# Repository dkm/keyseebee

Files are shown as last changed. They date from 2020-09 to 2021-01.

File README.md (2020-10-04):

# PouetPouet

The firmware is [Keyberon](https://github.com/TeXitoi/keyberon), a
pure rust firmware.

## Features

 * 60 keys, using Cherry MX switches, only 1U keycaps;
 * USB-C connector;
 * 1 STM32F072 MCU, with hardware USB DFU bootloader and crystal less USB;
 * Only onboard SMD component (except for the switches).

## Inspiration

 * [Keyseebee](https://github.com/TeXitoi/keyseebee) for being the «I will change it quickly and have something ready in an hour» base project (even if I ended up redoing most of the hardware design).
 * [Steamvan](https://github.com/jmdaly/steamvan) for some KiCad design ideas;
 * [help-14](https://github.com/help-14/mechanical-keyboard) for making a nice list of existing keyboard;
 * [Masterzen](http://www.masterzen.fr/2020/05/03/designing-a-keyboard-part-1/) and many others for writing online tutorials for newbies like me.

## Bill Of Materials

|Item |Package|Qty|Remarks |Price |
|---|---|--:|---|-----:|

## Compiling and flashing

Install the complete toolchain and utils:

```shell
curl https://sh.rustup.rs -sSf | sh
rustup target add thumbv6m-none-eabi
rustup component add llvm-tools-preview
cargo install cargo-binutils
sudo apt-get install dfu-util
```

Compile:

```shell
cd firmware
cargo objcopy --bin pouetpouet --release -- -O binary pouetpouet.bin
```

To flash using dfu-util, first put the board in dfu mode by pressing
BOOT, pressing and releasing RESET and releasing BOOT. Then:

```shell
dfu-util -d 0483:df11 -a 0 -s 0x08000000:leave -D pouetpouet.bin
```

The fist time, if the write fail, your flash might be protected. To
unprotect:

```shell
dfu-util -d 0483:df11 -a 0 -s 0x08000000:force:unprotect -D pouetpouet.bin
```

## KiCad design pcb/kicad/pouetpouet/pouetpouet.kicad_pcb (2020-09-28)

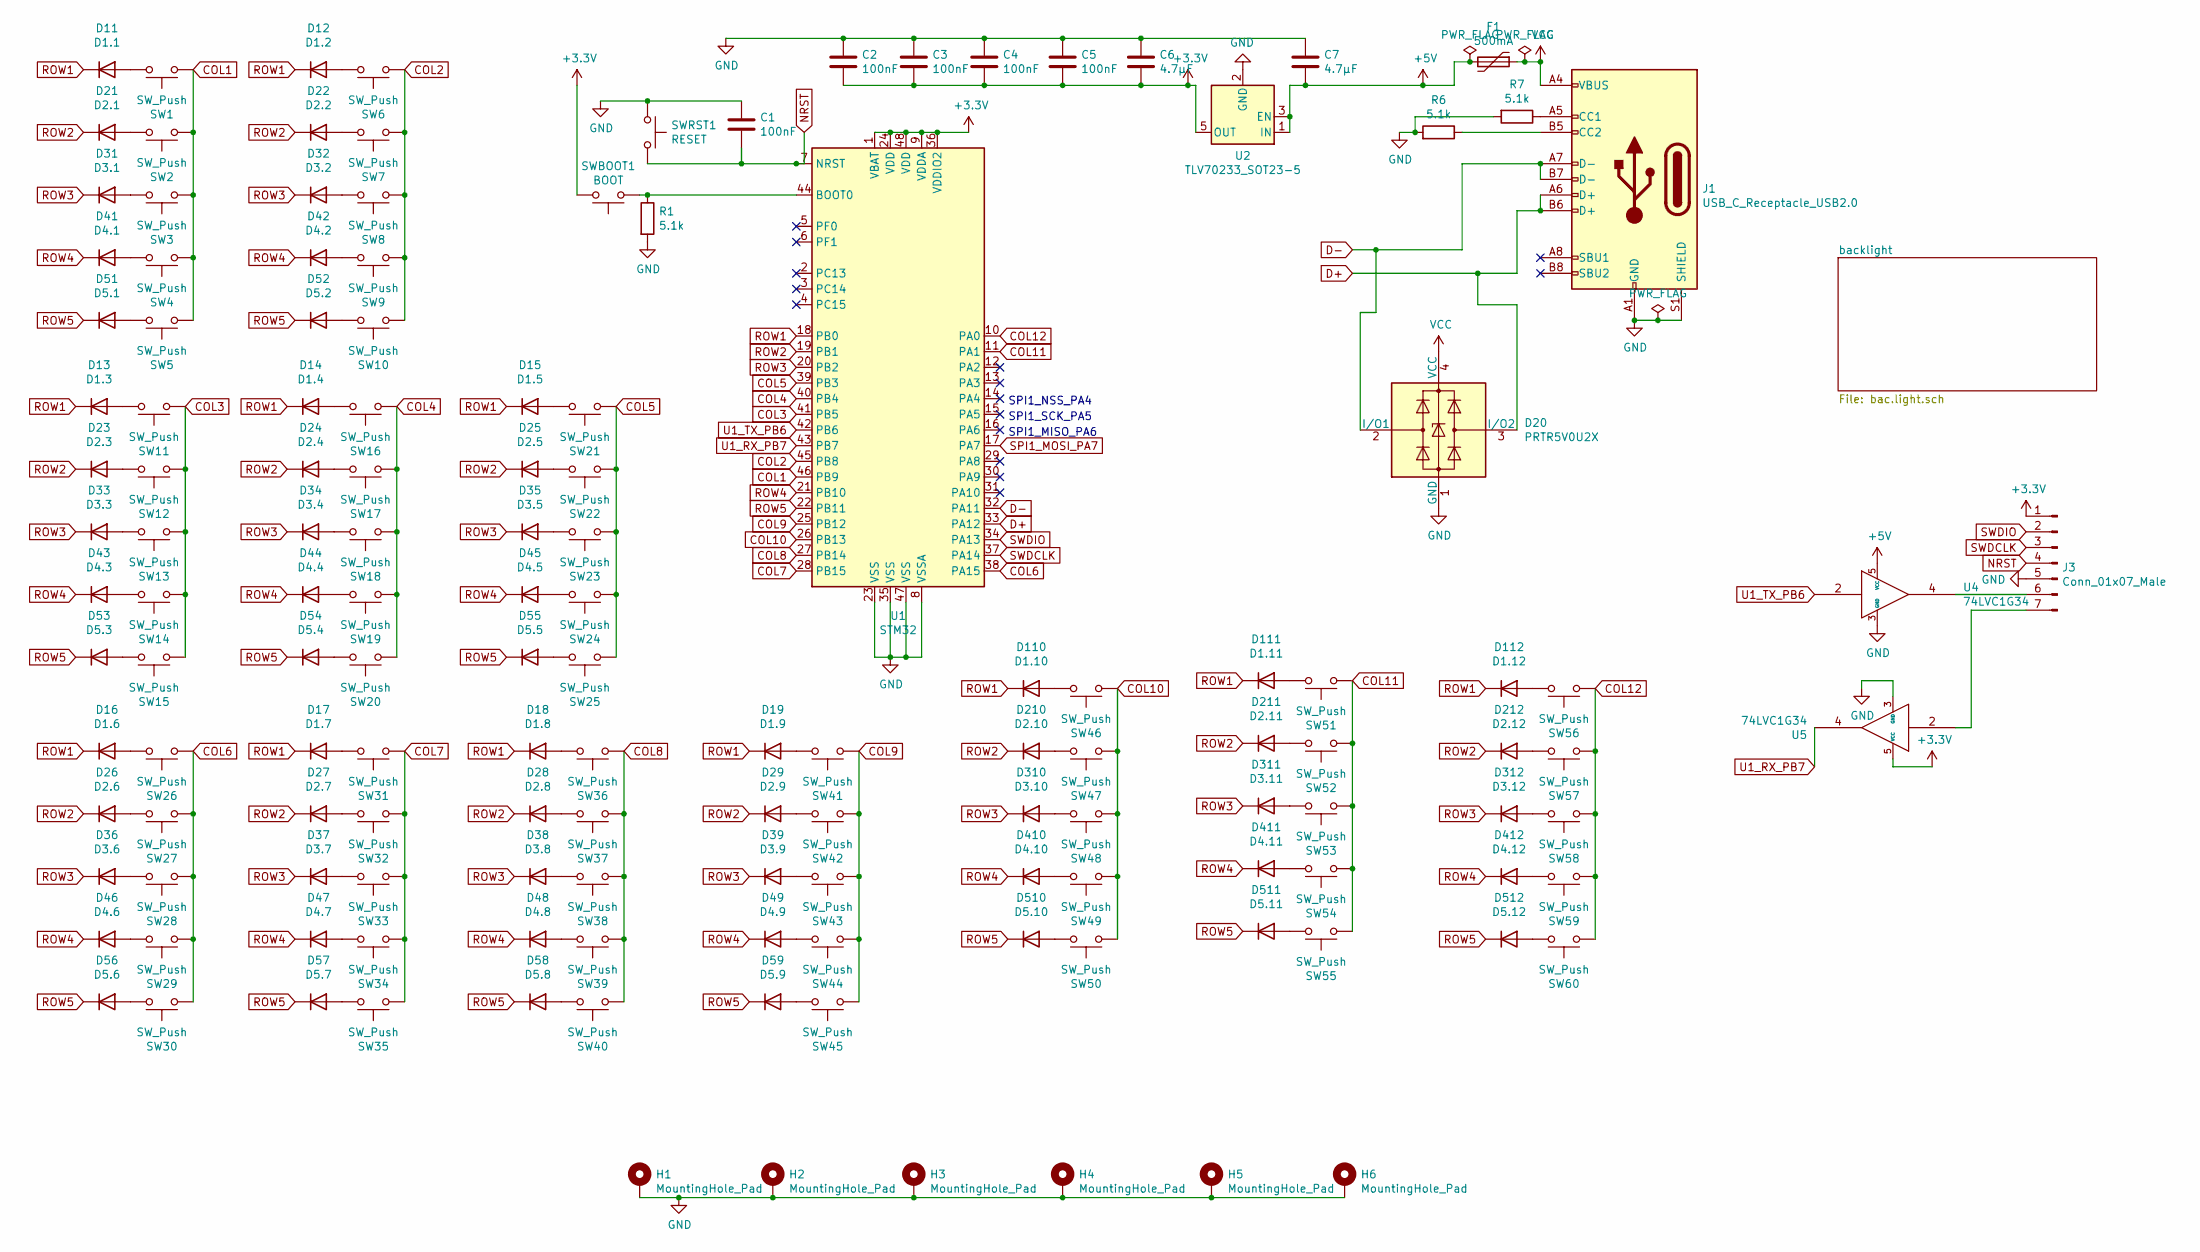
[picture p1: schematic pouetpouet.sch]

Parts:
C1, C2, C3, C4, C5: 100nF; C_0805_2012Metric_Pad1.15x1.40mm_HandSolder
C6, C7: 4.7µF; C_0805_2012Metric_Pad1.15x1.40mm_HandSolder
D11: D1.1; D_SOD-323
D12: D1.2; D_SOD-323
D13: D1.3; D_SOD-323
D14: D1.4; D_SOD-323
D15: D1.5; D_SOD-323
D16: D1.6; D_SOD-323
D17: D1.7; D_SOD-323
D18: D1.8; D_SOD-323
D19: D1.9; D_SOD-323
D20: PRTR5V0U2X; SOT-143
D21: D2.1; D_SOD-323
D22: D2.2; D_SOD-323
D23: D2.3; D_SOD-323
D24: D2.4; D_SOD-323
D25: D2.5; D_SOD-323
D26: D2.6; D_SOD-323
D27: D2.7; D_SOD-323
D28: D2.8; D_SOD-323
D29: D2.9; D_SOD-323
D31: D3.1; D_SOD-323
D32: D3.2; D_SOD-323
D33: D3.3; D_SOD-323
D34: D3.4; D_SOD-323
D35: D3.5; D_SOD-323
D36: D3.6; D_SOD-323
D37: D3.7; D_SOD-323
D38: D3.8; D_SOD-323
D39: D3.9; D_SOD-323
D41: D4.1; D_SOD-323
D42: D4.2; D_SOD-323
D43: D4.3; D_SOD-323
D44: D4.4; D_SOD-323
D45: D4.5; D_SOD-323
D46: D4.6; D_SOD-323
D47: D4.7; D_SOD-323
D48: D4.8; D_SOD-323
D49: D4.9; D_SOD-323
D51: D5.1; D_SOD-323
D52: D5.2; D_SOD-323
D53: D5.3; D_SOD-323
D54: D5.4; D_SOD-323
D55: D5.5; D_SOD-323
D56: D5.6; D_SOD-323
D57: D5.7; D_SOD-323
D58: D5.8; D_SOD-323
D59: D5.9; D_SOD-323
D110: D1.10; D_SOD-323
D111: D1.11; D_SOD-323
D112: D1.12; D_SOD-323
D210: D2.10; D_SOD-323
D211: D2.11; D_SOD-323
D212: D2.12; D_SOD-323
D310: D3.10; D_SOD-323
D311: D3.11; D_SOD-323
D312: D3.12; D_SOD-323
D410: D4.10; D_SOD-323
D411: D4.11; D_SOD-323
D412: D4.12; D_SOD-323
D510: D5.10; D_SOD-323
D511: D5.11; D_SOD-323
D512: D5.12; D_SOD-323
F1: 500mA; R_0805_2012Metric_Pad1.15x1.40mm_HandSolder
H1, H2, H3, H4, H5, H6: MountingHole_Pad; MountingHole_2.2mm_M2_Pad
J1: USB_C_Receptacle_USB2.0; USB_C_Receptacle_HRO_TYPE-C-31-M-12
J3: Conn_01x07_Male; Harwin_M20-89007xx_1x07_P2.54mm_Horizontal
R1, R6, R7: 5.1k; R_0805_2012Metric_Pad1.15x1.40mm_HandSolder
SW1, SW2, SW3, SW4, SW5, SW6, SW7, SW8, SW9, SW10, SW11, SW12, SW13, SW14, SW15, SW16, SW17, SW18, SW19, SW20, SW21, SW22, SW23, SW24, SW25, SW26, SW27, SW28, SW29, SW30, SW31, SW32, SW33, SW34, SW35, SW36, SW37, SW38, SW39, SW40, SW41, SW42, SW43, SW44, SW45, SW46, SW47, SW48, SW49, SW50, SW51, SW52, SW53, SW54, SW55, SW56, SW57, SW58, SW59, SW60: SW_Push; SW_Cherry_MX_1.00u_PCB
SWBOOT1: BOOT; SW_SPST_CK_RS282G05A3
SWRST1: RESET; SW_SPST_CK_RS282G05A3
U1: STM32; LQFP-48_7x7mm_P0.5mm
U2: TLV70233_SOT23-5; SOT-23-5
U4, U5: 74LVC1G34; SOT-353_SC-70-5

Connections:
+3V3: C2.2, C3.2, C4.2, C5.2, C6.2, J3.1, SWBOOT1.2, U1.1 (VBAT), U1.9 (VDDA), U1.24 (VDD), U1.36 (VDDIO2), U1.48 (VDD), U2.5 (OUT), U5.5 (VCC)
+5V: C7.2, F1.2, U2.1 (IN), U2.3 (EN), U4.5 (VCC); also elsewhere on the board
COL1: SW1.1, SW2.1, SW3.1, SW4.1, SW5.1, U1.46 (PB9)
COL2: SW6.1, SW7.1, SW8.1, SW9.1, SW10.1, U1.45 (PB8)
COL3: SW11.1, SW12.1, SW13.1, SW14.1, SW15.1, U1.41 (PB5)
COL4: SW16.1, SW17.1, SW18.1, SW19.1, SW20.1, U1.40 (PB4)
COL5: SW21.1, SW22.1, SW23.1, SW24.1, SW25.1, U1.39 (PB3)
COL6: SW26.1, SW27.1, SW28.1, SW29.1, SW30.1, U1.38 (PA15)
COL7: SW31.1, SW32.1, SW33.1, SW34.1, SW35.1, U1.28 (PB15)
COL8: SW36.1, SW37.1, SW38.1, SW39.1, SW40.1, U1.27 (PB14)
COL9: SW41.1, SW42.1, SW43.1, SW44.1, SW45.1, U1.25 (PB12)
COL10: SW46.1, SW47.1, SW48.1, SW49.1, SW50.1, U1.26 (PB13)
COL11: SW51.1, SW52.1, SW53.1, SW54.1, SW55.1, U1.11 (PA1)
COL12: SW56.1, SW57.1, SW58.1, SW59.1, SW60.1, U1.10 (PA0)
D+: D20.3 (I/O2), J1.A6 (D+), J1.B6 (D+), U1.33 (PA12)
D-: D20.2 (I/O1), J1.A7 (D-), J1.B7 (D-), U1.32 (PA11)
GND: C1.1, C2.1, C3.1, C4.1, C5.1, C6.1, C7.1, D20.1 (GND), H1.1, H2.1, H3.1, H4.1, H5.1, H6.1, J1.A1 (GND), J1.A12 (GND), J1.B1 (GND), J1.B12 (GND), J1.S1 (SHIELD), J3.5, R1.2, R6.2, R7.2, SWRST1.1, U1.8 (VSSA), U1.23 (VSS), U1.35 (VSS), U1.47 (VSS), U2.2 (GND), U4.3 (GND), U5.3 (GND); also elsewhere on the board
NRST: C1.2, J3.4, SWRST1.2, U1.7 (NRST)
unnamed: D11.2 (A), SW1.2
unnamed: D12.2 (A), SW6.2
unnamed: D13.2 (A), SW11.2
unnamed: D14.2 (A), SW16.2
unnamed: D15.2 (A), SW21.2
unnamed: D16.2 (A), SW26.2
unnamed: D17.2 (A), SW31.2
unnamed: D18.2 (A), SW36.2
unnamed: D19.2 (A), SW41.2
unnamed: D21.2 (A), SW2.2
unnamed: D22.2 (A), SW7.2
unnamed: D23.2 (A), SW12.2
unnamed: D24.2 (A), SW17.2
unnamed: D25.2 (A), SW22.2
unnamed: D26.2 (A), SW27.2
unnamed: D27.2 (A), SW32.2
unnamed: D28.2 (A), SW37.2
unnamed: D29.2 (A), SW42.2
unnamed: D31.2 (A), SW3.2
unnamed: D32.2 (A), SW8.2
unnamed: D33.2 (A), SW13.2
unnamed: D34.2 (A), SW18.2
unnamed: D35.2 (A), SW23.2
unnamed: D36.2 (A), SW28.2
unnamed: D37.2 (A), SW33.2
unnamed: D38.2 (A), SW38.2
unnamed: D39.2 (A), SW43.2
unnamed: D41.2 (A), SW4.2
unnamed: D42.2 (A), SW9.2
unnamed: D43.2 (A), SW14.2
unnamed: D44.2 (A), SW19.2
unnamed: D45.2 (A), SW24.2
unnamed: D46.2 (A), SW29.2
unnamed: D47.2 (A), SW34.2
unnamed: D48.2 (A), SW39.2
unnamed: D49.2 (A), SW44.2
unnamed: D51.2 (A), SW5.2
unnamed: D52.2 (A), SW10.2
unnamed: D53.2 (A), SW15.2
unnamed: D54.2 (A), SW20.2
unnamed: D55.2 (A), SW25.2
unnamed: D56.2 (A), SW30.2
unnamed: D57.2 (A), SW35.2
unnamed: D58.2 (A), SW40.2
unnamed: D59.2 (A), SW45.2
unnamed: D110.2 (A), SW46.2
unnamed: D111.2 (A), SW51.2
unnamed: D112.2 (A), SW56.2
unnamed: D210.2 (A), SW47.2
unnamed: D211.2 (A), SW52.2
unnamed: D212.2 (A), SW57.2
unnamed: D310.2 (A), SW48.2
unnamed: D311.2 (A), SW53.2
unnamed: D312.2 (A), SW58.2
unnamed: D410.2 (A), SW49.2
unnamed: D411.2 (A), SW54.2
unnamed: D412.2 (A), SW59.2
unnamed: D510.2 (A), SW50.2
unnamed: D511.2 (A), SW55.2
unnamed: D512.2 (A), SW60.2
unnamed: J1.A5 (CC1), R7.1
unnamed: J1.B5 (CC2), R6.1
unnamed: J3.6, U4.4
unnamed: J3.7, U5.2
unnamed: R1.1, SWBOOT1.1, U1.44 (BOOT0)
ROW1: D11.1 (K), D12.1 (K), D13.1 (K), D14.1 (K), D15.1 (K), D16.1 (K), D17.1 (K), D18.1 (K), D19.1 (K), D110.1 (K), D111.1 (K), D112.1 (K), U1.18 (PB0)
ROW2: D21.1 (K), D22.1 (K), D23.1 (K), D24.1 (K), D25.1 (K), D26.1 (K), D27.1 (K), D28.1 (K), D29.1 (K), D210.1 (K), D211.1 (K), D212.1 (K), U1.19 (PB1)
ROW3: D31.1 (K), D32.1 (K), D33.1 (K), D34.1 (K), D35.1 (K), D36.1 (K), D37.1 (K), D38.1 (K), D39.1 (K), D310.1 (K), D311.1 (K), D312.1 (K), U1.20 (PB2)
ROW4: D41.1 (K), D42.1 (K), D43.1 (K), D44.1 (K), D45.1 (K), D46.1 (K), D47.1 (K), D48.1 (K), D49.1 (K), D410.1 (K), D411.1 (K), D412.1 (K), U1.21 (PB10)
ROW5: D51.1 (K), D52.1 (K), D53.1 (K), D54.1 (K), D55.1 (K), D56.1 (K), D57.1 (K), D58.1 (K), D59.1 (K), D510.1 (K), D511.1 (K), D512.1 (K), U1.22 (PB11)
SPI1_MOSI_PA7: U1.17 (PA7); also elsewhere on the board
SWDCLK: J3.3, U1.37 (PA14)
SWDIO: J3.2, U1.34 (PA13)
U1_RX_PB7: U1.43 (PB7), U5.4
U1_TX_PB6: U1.42 (PB6), U4.2
VCC: D20.4 (VCC), F1.1, J1.A4 (VBUS), J1.A9 (VBUS), J1.B4 (VBUS), J1.B9 (VBUS)

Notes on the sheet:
SPI1_NSS_PA4
SPI1_SCK_PA5
SPI1_MISO_PA6

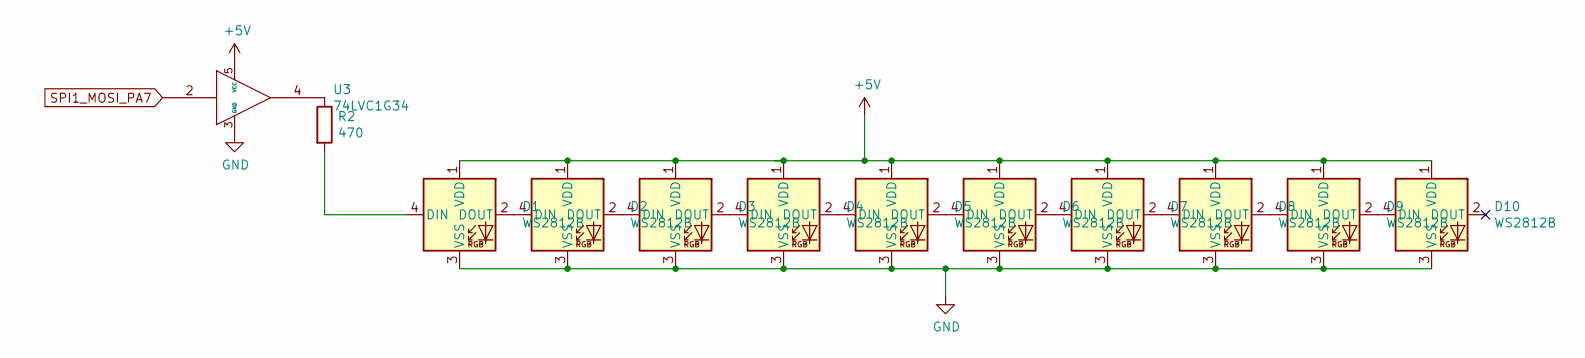
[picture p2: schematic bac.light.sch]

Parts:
D1, D2, D3, D4, D5, D6, D7, D8, D9, D10: WS2812B; LED_WS2812B_PLCC4_5.0x5.0mm_P3.2mm
R2: 470; R_0805_2012Metric_Pad1.15x1.40mm_HandSolder
U3: 74LVC1G34; SOT-353_SC-70-5

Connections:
+5V: D1.1 (VDD), D2.1 (VDD), D3.1 (VDD), D4.1 (VDD), D5.1 (VDD), D6.1 (VDD), D7.1 (VDD), D8.1 (VDD), D9.1 (VDD), D10.1 (VDD), U3.5 (VCC); also elsewhere on the board
GND: D1.3 (VSS), D2.3 (VSS), D3.3 (VSS), D4.3 (VSS), D5.3 (VSS), D6.3 (VSS), D7.3 (VSS), D8.3 (VSS), D9.3 (VSS), D10.3 (VSS), U3.3 (GND); also elsewhere on the board
unnamed: D1.2 (DOUT), D2.4 (DIN)
unnamed: D1.4 (DIN), R2.2
unnamed: D2.2 (DOUT), D3.4 (DIN)
unnamed: D3.2 (DOUT), D4.4 (DIN)
unnamed: D4.2 (DOUT), D5.4 (DIN)
unnamed: D5.2 (DOUT), D6.4 (DIN)
unnamed: D6.2 (DOUT), D7.4 (DIN)
unnamed: D7.2 (DOUT), D8.4 (DIN)
unnamed: D8.2 (DOUT), D9.4 (DIN)
unnamed: D9.2 (DOUT), D10.4 (DIN)
unnamed: R2.1, U3.4
SPI1_MOSI_PA7: U3.2; also elsewhere on the board

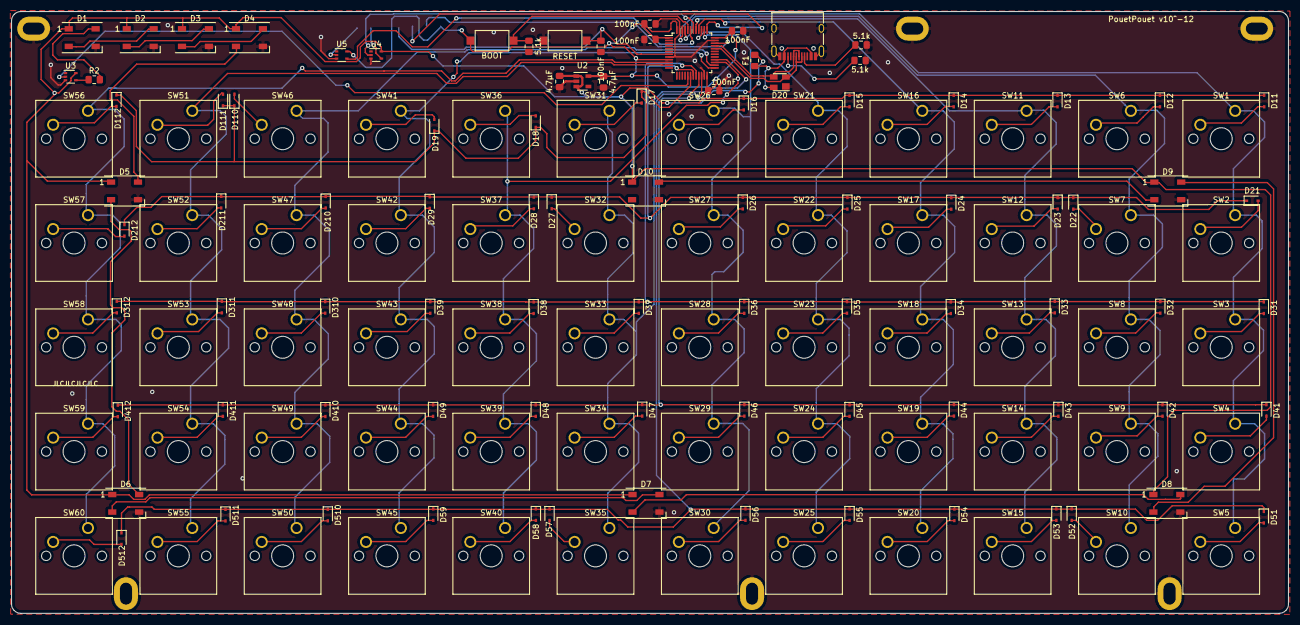
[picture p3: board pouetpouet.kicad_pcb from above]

Board: 2 copper layers, 232.6 x 109.6 mm, 158 parts (1 on the bottom side), 105 nets.

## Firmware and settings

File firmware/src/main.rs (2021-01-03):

#![no_main]
#![no_std]

// set the panic handler
use panic_halt as _;

extern crate smart_leds;
extern crate ws2812_spi;

use smart_leds::{brightness, colors, SmartLedsWrite, RGB8};

use ws2812_spi as ws2812;

use core::convert::Infallible;

use embedded_hal::digital::v2::{InputPin, OutputPin};

use generic_array::typenum::{U12, U5};

use hal::gpio::{gpioa, gpiob, Alternate, Input, Output, PullUp, PushPull, AF0};

use hal::prelude::*;

use embedded_hal::spi::FullDuplex;

use hal::usb;
use hal::{
    spi::{EightBit, Mode, Phase, Polarity},
    stm32, timers,
};

use keyberon::action::{k, l, m, Action, Action::*};
use keyberon::debounce::Debouncer;
use keyberon::impl_heterogenous_array;
use keyberon::key_code::KbHidReport;
use keyberon::key_code::KeyCode;
use keyberon::key_code::KeyCode::*;
use keyberon::layout::Layout;
use keyberon::matrix::{Matrix, PressedKeys};

use rtic::app;

use stm32f0xx_hal as hal;

use usb_device::bus::UsbBusAllocator;
use usb_device::class::UsbClass as _;
type Spi = hal::spi::Spi<
    stm32::SPI1,
    gpioa::PA5<Alternate<AF0>>,
    gpioa::PA6<Alternate<AF0>>,
    gpioa::PA7<Alternate<AF0>>,
    EightBit,
>;

type UsbClass = keyberon::Class<'static, usb::UsbBusType, Leds<Spi>>;

type UsbDevice = usb_device::device::UsbDevice<'static, usb::UsbBusType>;

trait ResultExt<T> {
    fn get(self) -> T;
}
impl<T> ResultExt<T> for Result<T, Infallible> {
    fn get(self) -> T {
        match self {
            Ok(v) => v,
            Err(e) => match e {},
        }
    }
}

pub struct Cols(
    gpioa::PA0<Input<PullUp>>,  // 12
    gpioa::PA1<Input<PullUp>>,  // 11
    gpiob::PB13<Input<PullUp>>, // 10
    gpiob::PB12<Input<PullUp>>, // 9
    gpiob::PB14<Input<PullUp>>, // 8
    gpiob::PB15<Input<PullUp>>, // 7
    gpioa::PA15<Input<PullUp>>, // 6
    gpiob::PB3<Input<PullUp>>,  // 5
    gpiob::PB4<Input<PullUp>>,  // 4
    gpiob::PB5<Input<PullUp>>,  // 3
    gpiob::PB8<Input<PullUp>>,  // 2
    gpiob::PB9<Input<PullUp>>,  // 1
);
impl_heterogenous_array! {
    Cols,
    dyn InputPin<Error = Infallible>,
    U12,
    [0, 1, 2, 3, 4, 5, 6, 7, 8, 9, 10, 11]
}

pub struct Rows(
    gpiob::PB0<Output<PushPull>>,
    gpiob::PB1<Output<PushPull>>,
    gpiob::PB2<Output<PushPull>>,
    gpiob::PB10<Output<PushPull>>,
    gpiob::PB11<Output<PushPull>>,
);
impl_heterogenous_array! {
    Rows,
    dyn OutputPin<Error = Infallible>,
    U5,
    [0, 1, 2, 3, 4]
}

#[derive(Debug, Clone, Copy, Eq, PartialEq)]
pub enum CustomActions {
    LightUp,
    LightDown,

    ModeCycle,
    ColorCycle,
}

#[rustfmt::skip]
pub static LAYERS: keyberon::layout::Layers<CustomActions> = &[
    &[
        &[k(Kb1),     k(Kb2),     k(Kb3),    k(Kb4),     k(Kb5),  k(Grave),  k(Kb6),    k(Kb7),      k(Kb8),   k(Kb9),    k(Kb0),    k(Minus)],
        &[k(Q),       k(W),       k(E),      k(R),       k(T),    k(Tab),    k(Y),      k(U),        k(I),     k(O),      k(P),      k(LBracket)],
        &[k(A),       k(S),       k(D),      k(F),       k(G),    k(BSpace), k(H),      k(J),        k(K),     k(L),      k(SColon), k(Quote)],
        &[k(Z),       k(X),       k(C),      k(V),       k(B),    k(Enter),  k(N),      k(M),        k(Comma), k(Dot),    k(Slash),  k(Bslash)  ],
        &[k(LCtrl),   l(1),       k(LGui),   k(LShift),  k(LAlt), k(Space),  k(RAlt),   k(RBracket), k(Equal), k(Delete), k(RShift), k(RCtrl)],

    ], &[
        &[k(F1),          k(F2),      k(F3), k(F4),  k(F5),  k(F6),     k(F7),     k(F8),   k(F9),     k(F10), k(F11), k(F12)],
        &[k(SysReq),      k(NumLock), Trans, Trans,  Trans,  k(Escape), k(Insert), k(PgUp), k(PgDown), Trans,  Trans,  Trans ],
        &[Trans    ,      Trans     , Trans, Trans,  Trans,  Trans,     k(Home),   k(Up),   k(End),    Trans,  Trans,  Trans ],
        &[k(NonUsBslash), Action::Custom(CustomActions::ColorCycle),      Trans, Trans,  Trans,  Trans,     k(Left),   k(Down), k(Right),  Trans,  Trans,  k(PgUp) ],
        &[Action::Custom(CustomActions::LightUp),          Trans,      Action::Custom(CustomActions::LightDown), Action::Custom(CustomActions::ModeCycle),  Trans,  Trans,     Trans,     Trans,   Trans,     Trans,  Trans, Trans],
    ],
];

pub struct Leds<SPI> {
    ws: ws2812::Ws2812<SPI>,
    leds: [RGB8; 10],
}

impl<SPI, E> keyberon::keyboard::Leds for Leds<SPI>
where
    SPI: FullDuplex<u8, Error = E>,
{
    fn caps_lock(&mut self, status: bool) {
        if status {
            self.leds[0] = colors::BLUE;
        } else {
            self.leds[0] = colors::BLACK;
        }
        self.ws.write(brightness(self.leds.iter().cloned(), 10));
    }

    fn num_lock(&mut self, status: bool) {
        if status {
            self.leds[1] = colors::GREEN;
        } else {
            self.leds[1] = colors::BLACK;
        }
        self.ws.write(brightness(self.leds.iter().cloned(), 10));
    }

    fn compose(&mut self, status: bool) {
        if status {
            self.leds[3] = colors::VIOLET;
        } else {
            self.leds[3] = colors::BLACK;
        }
        self.ws.write(brightness(self.leds.iter().cloned(), 10));
    }
}

#[derive(Debug, Clone, Copy, Eq, PartialEq)]
pub enum BacklightMode {
    Off,
    Solid(RGB8),
    K2000(RGB8, usize, usize, bool),
    Fire,
    Breath(RGB8, bool),
}

pub struct Backlight {
    mode: BacklightMode,
    brightness: u8,
}

trait ColorSeq {
    fn next_color(&self) -> RGB8;
}

const COLORS_SEQ: [RGB8; 5] = [
    colors::RED,
    colors::GREEN,
    colors::BLUE,
    colors::VIOLET,
    colors::YELLOW,
];

impl ColorSeq for RGB8 {
    fn next_color(&self) -> RGB8 {
        let mut next = false;

        for c in &COLORS_SEQ {
            if next {
                return *c;
            }

            if *self == *c {
                next = true;
            }
        }

        COLORS_SEQ[0]
    }
}

impl Backlight {
    pub fn next_mode(&mut self) {
        self.mode = match self.mode {
            BacklightMode::Off => BacklightMode::Solid(colors::RED),
            BacklightMode::Solid(_) => BacklightMode::K2000(colors::RED, 0, 0, true),
            BacklightMode::K2000(_, _, _, _) => BacklightMode::Fire,
            BacklightMode::Fire => BacklightMode::Breath(colors::RED, true),
            BacklightMode::Breath(_, _) => BacklightMode::Off,
        }
    }

    pub fn next_color(&mut self) {
        self.mode = match self.mode {
            BacklightMode::Solid(c) => BacklightMode::Solid(c.next_color()),
            BacklightMode::Breath(c, dir) => BacklightMode::Breath(c.next_color(), dir),
            BacklightMode::K2000(c, s, i, dir) => BacklightMode::K2000(c.next_color(), s, i, dir),
            any => any,
        }
    }

    pub fn refresh_leds(&mut self, leds: &mut Leds<Spi>) {
        self.mode = match self.mode {
            BacklightMode::Off => {
                for l in leds.leds[4..].iter_mut() {
                    *l = colors::BLACK;
                }
                BacklightMode::Off
            }

            BacklightMode::Solid(c) => {
                for l in leds.leds[4..].iter_mut() {
                    *l = c;
                }
                BacklightMode::Solid(c)
            }

            BacklightMode::Breath(c, dir) => {
                for l in leds.leds[4..].iter_mut() {
                    *l = c;
                }

                let mut new_dir = dir;
                if dir {
                    if self.brightness == 100 {
                        self.brightness -= 1;
                        new_dir = false;
                    }
                    self.brightness += 1;
                } else {
                    if self.brightness == 0 {
                        self.brightness += 1;
                        new_dir = true;
                    }
                    self.brightness -= 1;
                }
                BacklightMode::Breath(c, new_dir)
            }

            BacklightMode::K2000(c, step, index, dir) => {
                let mut new_dir = dir;
                let mut new_index = index;

                let mut step = step + 1;

                if step == 100 {
                    step = 0;

                    if new_index == 0 && !dir {
                        new_index = 0;
                        new_dir = true;
                    } else if new_index == 5 && dir {
                        new_index = 5;
                        new_dir = false;
                    } else {
                        new_index = if dir { index + 1 } else { index - 1 };
                    }
                }

                for (i, l) in leds.leds[4..].iter_mut().enumerate() {
                    if i == new_index {
                        *l = c;
                    } else {
                        *l = colors::BLACK;
                    }
                }
                BacklightMode::K2000(c, step, new_index as usize, new_dir)
            }
            any => any,
        };

        leds.ws
            .write(brightness(leds.leds.iter().cloned(), self.brightness));
    }
}

#[app(device = crate::hal::pac, peripherals = true)]
const APP: () = {
    struct Resources {
        usb_dev: UsbDevice,
        usb_class: UsbClass,
        matrix: Matrix<Cols, Rows>,
        debouncer: Debouncer<PressedKeys<U5, U12>>,
        layout: Layout<CustomActions>,
        timer: timers::Timer<stm32::TIM3>,

        backlight: Backlight,
    }

    #[init]
    fn init(mut c: init::Context) -> init::LateResources {
        static mut USB_BUS: Option<UsbBusAllocator<usb::UsbBusType>> = None;

        let mut rcc = c
            .device
            .RCC
            .configure()
            .hsi48()
            .enable_crs(c.device.CRS)
            .sysclk(48.mhz())
            .pclk(24.mhz())
            .freeze(&mut c.device.FLASH);

        let gpioa = c.device.GPIOA.split(&mut rcc);
        let gpiob = c.device.GPIOB.split(&mut rcc);

        let usb = usb::Peripheral {
            usb: c.device.USB,
            pin_dm: gpioa.pa11,
            pin_dp: gpioa.pa12,
        };
        *USB_BUS = Some(usb::UsbBusType::new(usb));
        let usb_bus = USB_BUS.as_ref().unwrap();

        // Handling of ws2812 leds

        let pa5 = gpioa.pa5; // sck
        let pa6 = gpioa.pa6; // miso
        let pa7 = gpioa.pa7; // mosi

        // Configure pins for SPI
        let (sck, miso, mosi) = cortex_m::interrupt::free(move |cs| {
            (
                pa5.into_alternate_af0(cs),
                pa6.into_alternate_af0(cs),
                pa7.into_alternate_af0(cs),
            )
        });

        const MODE: Mode = Mode {
            polarity: Polarity::IdleHigh,
            phase: Phase::CaptureOnSecondTransition,
        };
        let spi = Spi::spi1(
            c.device.SPI1,
            (sck, miso, mosi),
            MODE,
            3_000_000.hz(),
            &mut rcc,
        );

        // ws2812
        let ws = ws2812::Ws2812::new(spi);

        let mut leds = Leds {
            ws,
            leds: [colors::BLACK; 10],
        };
        leds.ws.write(leds.leds.iter().cloned()).unwrap();

        let usb_class = keyberon::new_class(usb_bus, leds);
        let usb_dev = keyberon::new_device(usb_bus);

        let mut timer = timers::Timer::tim3(c.device.TIM3, 1.khz(), &mut rcc);
        timer.listen(timers::Event::TimeOut);

        let pa15 = gpioa.pa15;
        let pa1 = gpioa.pa1;
        let pa0 = gpioa.pa0;

        let matrix = cortex_m::interrupt::free(move |cs| {
            Matrix::new(
                Cols(
                    pa0.into_pull_up_input(cs),
                    pa1.into_pull_up_input(cs),
                    gpiob.pb13.into_pull_up_input(cs),
                    gpiob.pb12.into_pull_up_input(cs),
                    gpiob.pb14.into_pull_up_input(cs),
                    gpiob.pb15.into_pull_up_input(cs),
                    pa15.into_pull_up_input(cs),
                    gpiob.pb3.into_pull_up_input(cs),
                    gpiob.pb4.into_pull_up_input(cs),
                    gpiob.pb5.into_pull_up_input(cs),
                    gpiob.pb8.into_pull_up_input(cs),
                    gpiob.pb9.into_pull_up_input(cs),
                ),
                Rows(
                    gpiob.pb0.into_push_pull_output(cs),
                    gpiob.pb1.into_push_pull_output(cs),
                    gpiob.pb2.into_push_pull_output(cs),
                    gpiob.pb10.into_push_pull_output(cs),
                    gpiob.pb11.into_push_pull_output(cs),
                ),
            )
        });

        init::LateResources {
            usb_dev,
            usb_class,
            timer,
            debouncer: Debouncer::new(PressedKeys::default(), PressedKeys::default(), 5),
            matrix: matrix.get(),
            layout: Layout::new(LAYERS),

            backlight: Backlight {
                mode: BacklightMode::Off,
                brightness: 8,
            },
        }
    }

    #[task(binds = USB, priority = 4, resources = [usb_dev, usb_class])]
    fn usb_rx(c: usb_rx::Context) {
        if c.resources.usb_dev.poll(&mut [c.resources.usb_class]) {
            c.resources.usb_class.poll();
        }
    }

    #[task(
        binds = TIM3,
        priority = 2,
        resources = [matrix, debouncer, timer, layout, usb_class, backlight],
    )]
    fn tick(c: tick::Context) {
        c.resources.timer.wait().ok();

        for event in c
            .resources
            .debouncer
            .events(c.resources.matrix.get().unwrap())
        {
            c.resources.layout.event(event);
        }
        let mut usb_class = c.resources.usb_class;
        let backlight = c.resources.backlight;

        match c.resources.layout.tick() {
            keyberon::layout::CustomEvent::Release(CustomActions::LightUp) => {
                let bl_val = &mut backlight.brightness;
                *bl_val = if *bl_val == 100 { 100 } else { *bl_val + 1 };
                usb_class.lock(|k| {
                    let leds = k.device_mut().leds();
                    leds.ws
                        .write(brightness(leds.leds.iter().cloned(), *bl_val));
                });
            }
            keyberon::layout::CustomEvent::Release(CustomActions::LightDown) => {
                let bl_val = &mut backlight.brightness;
                *bl_val = if *bl_val == 0 { 0 } else { *bl_val - 1 };
                usb_class.lock(|k| {
                    let leds = k.device_mut().leds();
                    leds.ws
                        .write(brightness(leds.leds.iter().cloned(), *bl_val));
                });
            }
            keyberon::layout::CustomEvent::Release(CustomActions::ColorCycle) => {
                backlight.next_color();
            }
            keyberon::layout::CustomEvent::Release(CustomActions::ModeCycle) => {
                backlight.next_mode();
            }

            _ => (),
        }

        usb_class.lock(|k| {
            backlight.refresh_leds(&mut k.device_mut().leds());
        });

        c.resources.layout.tick();
        send_report(c.resources.layout.keycodes(), &mut usb_class);
    }

    extern "C" {
        fn CEC_CAN();
    }
};

fn send_report(iter: impl Iterator<Item = KeyCode>, usb_class: &mut resources::usb_class<'_>) {
    use rtic::Mutex;
    let report: KbHidReport = iter.collect();
    if usb_class.lock(|k| k.device_mut().set_keyboard_report(report.clone())) {
        while let Ok(0) = usb_class.lock(|k| k.write(report.as_bytes())) {}
    }
}

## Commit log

2020-09-02 WIP for ortho 12x5
    [right.kicad_pcb, right.sch]
2020-09-06 WIP: some more routing
    [right.kicad_pcb, right.sch]
2020-09-07 WIP routing
    [right.kicad_pcb]
2020-09-09 WIP: routing, changed visual layout of diodes
    let go of nice diode array, too hard to route
    [right.kicad_pcb]
2020-09-09 WIP DRC and unconnected sw
    [right.kicad_pcb]
2020-09-09 WIP: routing complete
    [right.kicad_pcb]
2020-09-11 WIP: use more std footprint for MX only
    - reverse switch to match footprint
    - correct all DRC issues
    - simplify some routes.
    [right.kicad_pcb, right.sch]
2020-09-17 wip
    change footprint for debug pins, MCU, correctly route WS2812
    [pouetpouet.kicad_pcb, pouetpouet.sch]
2020-09-23 change LDO, add filter on USB, move capacitors
    [bac.light.sch, pouetpouet.kicad_pcb, pouetpouet.sch]
2020-09-24 WIP.
    add buffer for rx/tx pad to level up the signal from 3.3 to 5.
    [bac.light.sch, pouetpouet.kicad_pcb, pouetpouet.sch]
2020-09-25 move capacitor for all VDDs
    [pouetpouet.kicad_pcb, pouetpouet.sch]
2020-09-26 change ESD part, better handling mounting hole, remove unused pin on debug connector
    [pouetpouet.kicad_pcb, pouetpouet.sch]
2020-09-27 fix buffer for RX pin
    [pouetpouet.kicad_pcb, pouetpouet.sch]
2020-09-28 wip: update readme, fix ERC errors
    [pouetpouet.kicad_pcb, pouetpouet.sch]
